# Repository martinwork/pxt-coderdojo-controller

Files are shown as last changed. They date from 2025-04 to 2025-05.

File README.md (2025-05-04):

# pxt-coderdojo-controller
This is an open-source, low-cost, do-it-yourself game controller for the micro:bit. You cannot purchase a finished product. Instead, you'll need to gather all the components and assemble it yourself or with your class.  
[Read more in the hardware section for a detailed building guide](https://github.com/jimd80/pxt-coderdojo-controller/tree/main/hardware)

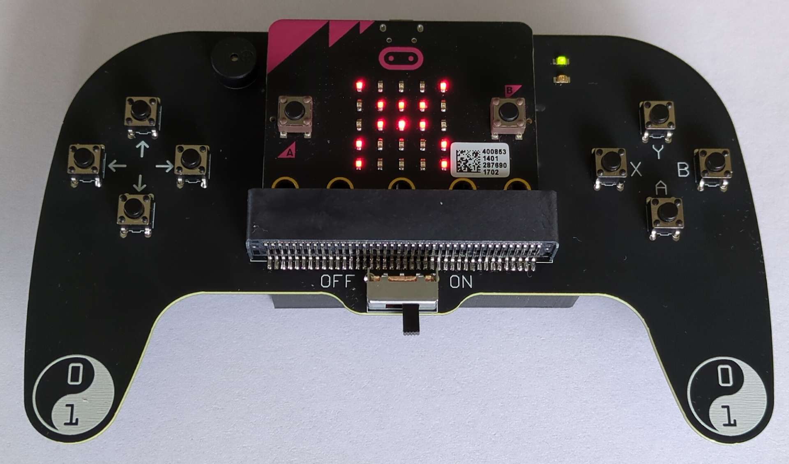
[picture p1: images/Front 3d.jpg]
Controller front image

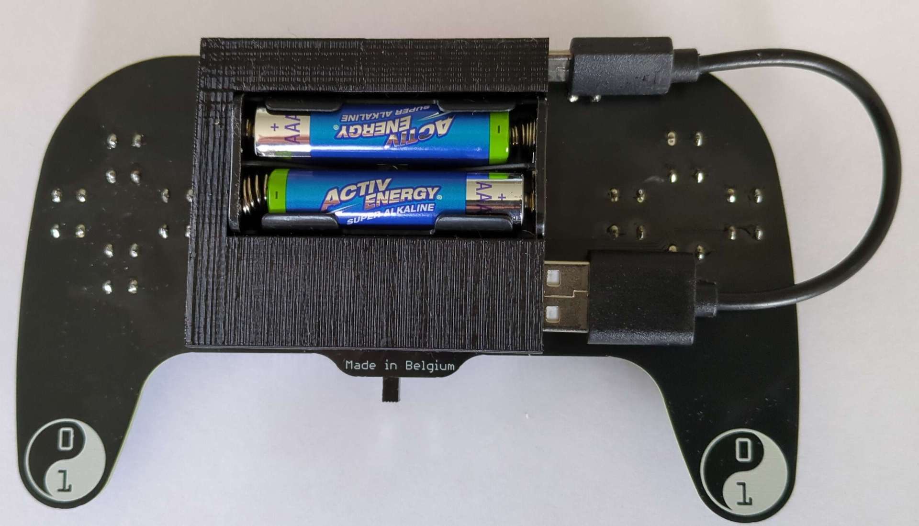
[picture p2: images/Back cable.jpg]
Controller back image


## Features
* 8 buttons: Up, Down, Left, Right, X, Y, A, B
* 2x AAA batteries, On/Off switch, and LED indicator
* Built-in speaker and customizable red LED
* Micro USB cable storage compartment
* Protection against short circuits and incorrect I/O usage
* Compatible with micro:bit v1.x and v2.x
* Over 100 hours of battery life

## Usage
Creating software for this controller can be done with [Microsoft MakeCode for micro:bit](https://makecode.microbit.org/)
* Create a new project and give it a name of your choice
* Click on Extensions in the block menu
* Search for coderDojo-controller and click on the thumbnail

After adding the extension, you'll find the specific blocks for this controller under ``Dojo Controller``

The blocks work the same as the standard micro:bit A and B buttons and can be used in 2 ways:  

* An event driven approach: use the ``on button pressed`` block. The code inside gets executed when a button is pressed/clicked. The behaviour can be changed to execute the code if the button is released instead.

```blocks
coderDojoController.onButtonPress(CoderDojoButtonID.X, CoderDojoButtonEvent.Pressed, function () {
    coderDojoController.setRedLed(CoderDojoLedState.On)
})
```

```blocks
coderDojoController.onButtonPress(CoderDojoButtonID.X, CoderDojoButtonEvent.Released, function () {
    coderDojoController.setRedLed(CoderDojoLedState.Off)
})
```

* Alternatively, a loop driven approach can be used with a standard ``if`` block combined with the ``button is pressed`` function. The code inside the ``if`` block will be executed multiple times, as long as the button is being pressed.

```blocks
basic.forever(function () {
    if (coderDojoController.buttonIsPressed(CoderDojoButton.X, CoderDojoButtonState.Pressed)) {
        coderDojoController.setRedLed(CoderDojoLedState.On)
    } else {
        coderDojoController.setRedLed(CoderDojoLedState.Off)
    }
})
```

Note that the A and B buttons on the micro:bit have the same function as the A and B buttons on the controller. You can use the extension without the controller hardware and have the extra buttons available when plugged into the controller.

## Build
cd into project folder  
npm install pxt  
pxt target microbit  
pxt gendocs --locs  
if needed: update translations in _locales/  
pxt build  

## Supported targets

* for PXT/microbit
(The metadata above is needed for package search.)

## License

MIT  

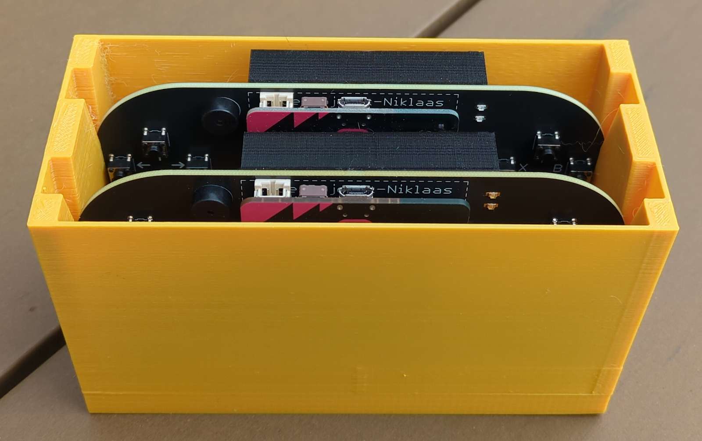
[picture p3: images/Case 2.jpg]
PCB Components


```package
coderdojo-controller=github:jimd80/pxt-coderdojo-controller
```

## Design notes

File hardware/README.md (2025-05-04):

## Hardware building guide
The (empty) PCB can be easily manufactured by any PCB company, for example JLCPCB which is known as the cheapest. The cable holder at the back can be 3D printed with any 3D printer, for example the affordable Creality Ender V2 or V3.

Other parts can be ordered at various electronics suppliers such as LCSC, Aliexpress, Digikey, Farnell, ... The most difficult part to source will be the Micro:bit EDGE Connector. This needs to be the horizontal SMD type. Start finding this connector first before deciding to build this project.

Soldering can be done with (Lead free) soldering paste and a reflow oven, or if you are a bit handy it can also be done with a classical soldering iron, lead-free soldering wire and some flux. In that case it will be handy to have something to keep the parts in place while soldering, such as a screwdriver.

## Tools needed

You'll needs some tools and skills to build this project.
- A soldering iron and lead-free soldering wire
- Optionally, a reflow oven OR a hot air gun. Using this option you'll also need lead-free solder paste, such as Chipquik TS391SNL
- Recommended: Flux, such as Chipquik SMD291NL
- Cutting plier

## Step 1: Ordering the parts
Check out the [Bill of materials](https://github.com/jimd80/pxt-coderdojo-controller/blob/main/hardware/Bom.ods?raw=true). Parts can be ordered at various suppliers.

Part number      |Reference	            |Description                      |Qty|Price|Order link example|
:----------------|:---------------------|:--------------------------------|--:|----:|:-----------------|
R1,2,3,4,8,9     |Res 1K SMD0805        |Resistor 1K / 1% / 0,1W / 0805   |  6|€0.06|[LCSC](https://www.lcsc.com/product-detail/Chip-Resistor-Surface-Mount_YAGEO-RC0805FR-071KL_C95781.html)|
R5               |Res 100R SMD0805      |Resistor 100R / 1% / 0,1W / 0805 |  1|€0.01|[LCSC](https://www.lcsc.com/product-detail/Chip-Resistor-Surface-Mount_YAGEO-RC0805FR-07100RL_C105577.html)|
R6,7             |Res 470R SMD0805      |Resistor 470R / 1% / 0,1W / 0805 |  2|€0.02|[LCSC](https://www.lcsc.com/product-detail/Chip-Resistor-Surface-Mount_YAGEO-RC0805FR-07470RL_C114564.html)|
C1,2 (Optional)  |Cap 4u7 16v SMD1206   |Capacitor 4u7 / 16V / SMD 1206   |  2|€0.04|[LCSC](https://www.lcsc.com/product-detail/Multilayer-Ceramic-Capacitors-MLCC-SMD-SMT_Samsung-Electro-Mechanics-CL31B475KBHNNNE_C51205.html)|
LD1              |LED Red SMD0805       |Led Red SMD 0805                 |  1|€0.02|[LCSC](https://www.lcsc.com/product-detail/LED-Indication-Discrete_XINGLIGHT-XL-2012SURC_C965812.html)|
LD2              |LED Green SMD0805     |Led Green SMD 0805               |  1|€0.02|[LCSC](https://www.lcsc.com/product-detail/LED-Indication-Discrete_XINGLIGHT-XL-2012UGC_C965815.html)|
F1               |Polyfuse 500mA SMD1812|Polyfuse 30V / 500mA / SMD 1812  |  1|€0.08|[Aliexpress](https://www.aliexpress.com/item/1005006431435556.html)|
BUZ1             |9042 16R Passive      |Passive piezo sounder 3-5v       |  1|€0.19|[Aliexpress](https://www.aliexpress.com/item/1005006230919996.html)|
SW1,2,3,4,6,7,8,9|Pushbutton 6x6x5mm    |Pushbutton (on)-off 6x6x5mm      |  8|€0.05|[Aliexpress](https://www.aliexpress.com/item/1005001897291190.html)|
SW5              |Switch SS-12F23       |Slider switch 50v/0,5A spdt      |  1|€0.08|[Aliexpress](https://www.aliexpress.com/item/1005004508647910.html)|
BATT1            |2XAAA Battery Box     |Battery holder 2x AAA center hole|  1|€0.36|[Aliexpress](https://www.aliexpress.com/item/1005006274732583.html)|
J1               |Edge connector hor SMD|Micro:bit edge connector SMD/hor |  1|€0.85|[Aliexpress](https://www.aliexpress.com/item/1005006206948907.html)|
Other            |SMTSO M3 1ET          |SMD M3 Nut Length 1,5 + 1mm      |  1|€0.22|[Aliexpress](https://www.aliexpress.com/item/1005007226371037.html)|
Other            |Screw M3x6            |Screw M3x6 countersunk           |  1|€0.04|[Aliexpress](https://www.aliexpress.com/item/4000983507018.html)|

- C1 and C2 are not really required but can avoid software resets when shaking the controller heavilly
- BUZ1 is not required if using a micro:bit v2 or if sound is not preferred
- The most difficult part to find will be the EDGE connector, this needs to be the horizontal SMD version, and needs to look exactely like this

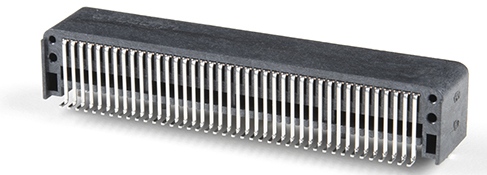
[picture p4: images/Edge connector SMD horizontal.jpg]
EDGE Connector


## Step 2: Ordering the PCB
The PCB (without components) needs to be manufactored by a company. These are the instructions for JLCPCB.
- Go to (https://jlcpcb.com)
- Choose "Add gerber file" and upload [CoderDojo Controller JLCPCB order.zip](https://github.com/jimd80/pxt-coderdojo-controller/blob/main/hardware/CoderDojo%20Controller%20JLCPCB%20order.zip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)
- Select your desired quantity (the more the cheaper per board)
- Change PCB Color to Black
- Change Surface Finish to LeadFree HASL (If ROHS is required in your country, always the case for the EU)
- Choose Mark on PCB: Remove Mark  
All other options are oke by default. Complete the order process.

## Step 3: 3D Print the cable holder
This step is not required if you don't want to have the cable storage at the back of the controller. In that case, the screw needs to be M3x5 instead of M3x6.
- Download [Cable holder 3D Print.stl](https://github.com/jimd80/pxt-coderdojo-controller/blob/main/hardware/CAD%20Files/Cable%20holder%203D%20Print.stl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)
- Process the file in your slicer. Recommended layer height is 0.2mm and recommended speed is 50mm/s
- Print it, preferable with black PETG as this is more fire resistant than PLA or ABS

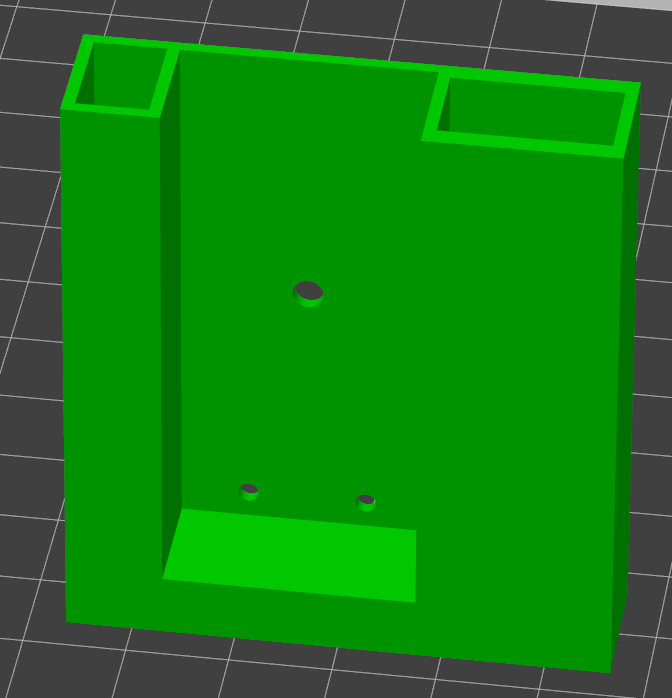
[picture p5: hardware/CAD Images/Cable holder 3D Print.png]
Cable holder


## Step 4: Solder the SMD parts
In the [Bill of materials](https://github.com/jimd80/pxt-coderdojo-controller/blob/main/hardware/Bom.ods?raw=true) you'll find which parts belongs to which part numbers printed on the PCB (such as R1, C1, ...). Only for the 2 LED's the direction of the part (polarity) matters. There is usually an indicator, like a small green dot or a line) that should point in the direction of the arrow on the PCB.
Also solder the special M3 nut in the middle. Avoid putting excess solder at the back side as that surface needs to stay flat for the battery box.

Soldering SMD parts can be done in several ways, there are many tutorials online such as https://www.youtube.com/watch?v=hoLf8gvvXXU or https://www.youtube.com/watch?v=fYInlAmPnGo

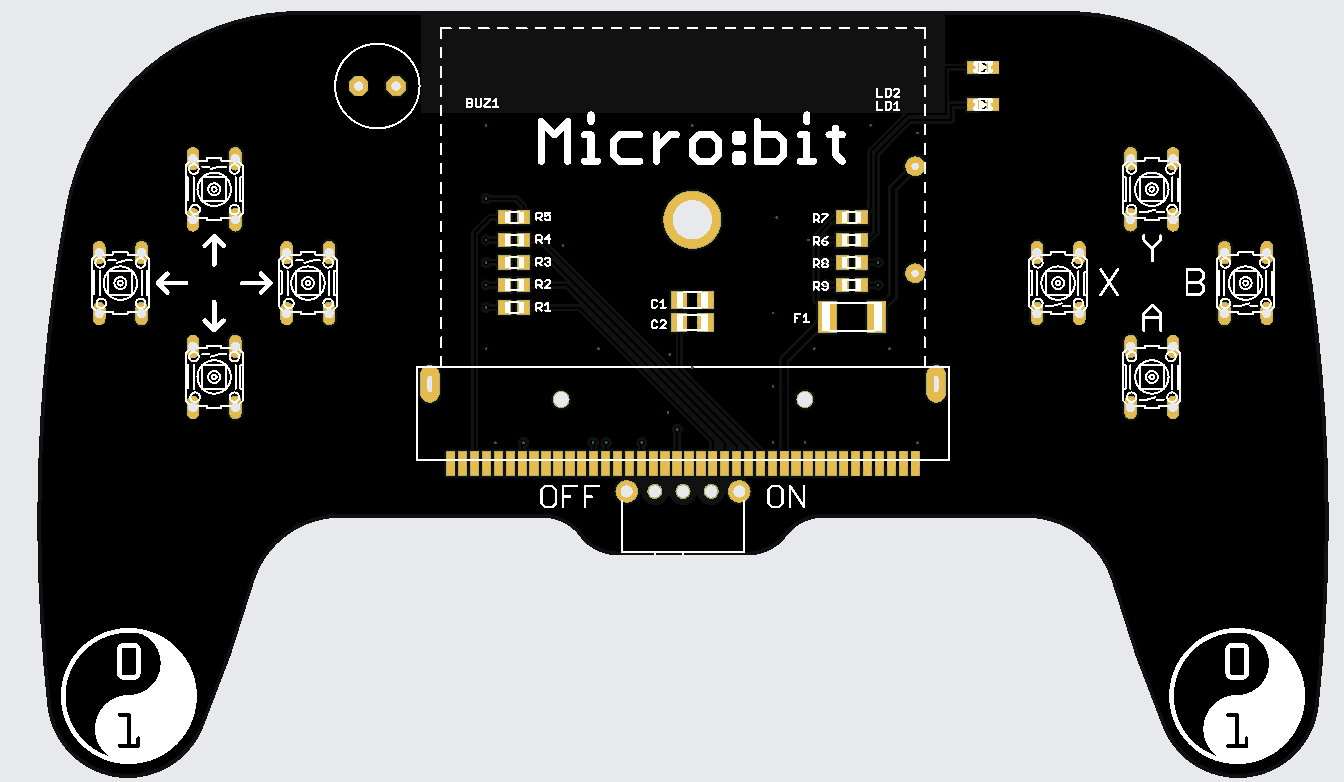
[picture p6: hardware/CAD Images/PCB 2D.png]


## Step 5: Solder the Edge connector
The EDGE connector is preferably soldered with a soldering iron as it is not clear if it can withstand 240 degrees hot air required for lead-free soldering. Use extra flux to create smooth joints. After soldering, remove the flux with isopropyl alcohol.

## Step 6: Solder the through hole parts
Next, solder the switches and the speaker with a soldering iron and soldering wire. Cut off the excess leads and smoothen the sharp edges at the back with a small file or sanding paper (be careful to not damage the pcb)

## Step 7: Mount the battery box and cable holder
Next, put the battery box through the printed cable holder at the back of the pcb, and fix it with a 6mm M3 screw (conical head). Then, solder the 2 leads of the battery box and cut the excess wire. Note that the leads of the battery box require decent heating to attach to the solder, as these leads are not pre-tinned as you would normally expect. On my prototype, I had regular software resets due to a poor contact due to insufficient heating. The soldering joint looked good, but was not really bounded.

## Step 8: Ready to power up
Always make sure to put the power switch to the OFF position when placing or removing the micro:bit.

Enjoy!

## Optional: Print a storage case
STL files are available in the CAD Files folder for printing a storage case from 2 till 7 controllers. The bottom notch will prevent the contoller to fit nicely when the power button is still on (preventing battery drain)  

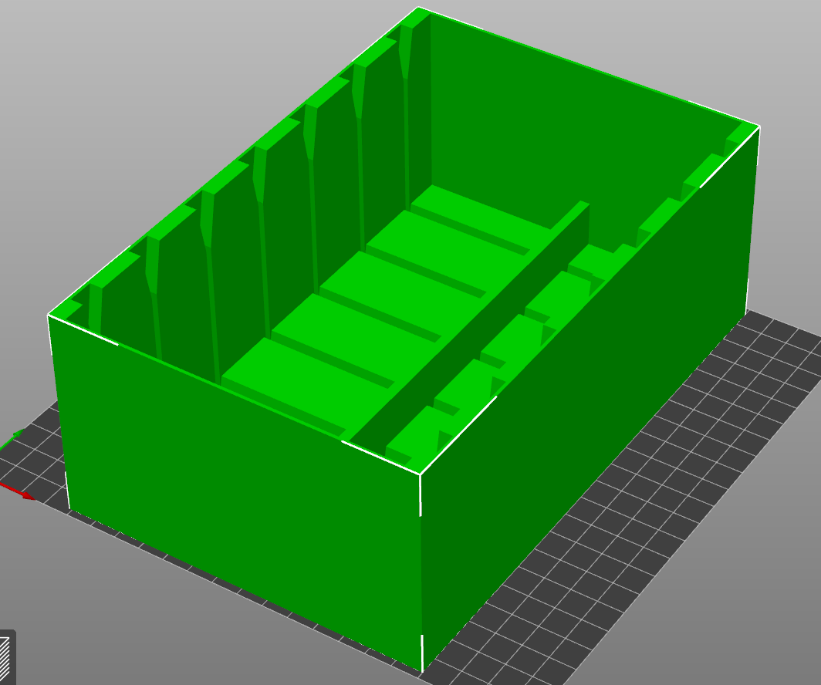
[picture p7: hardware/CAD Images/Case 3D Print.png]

PCB Components

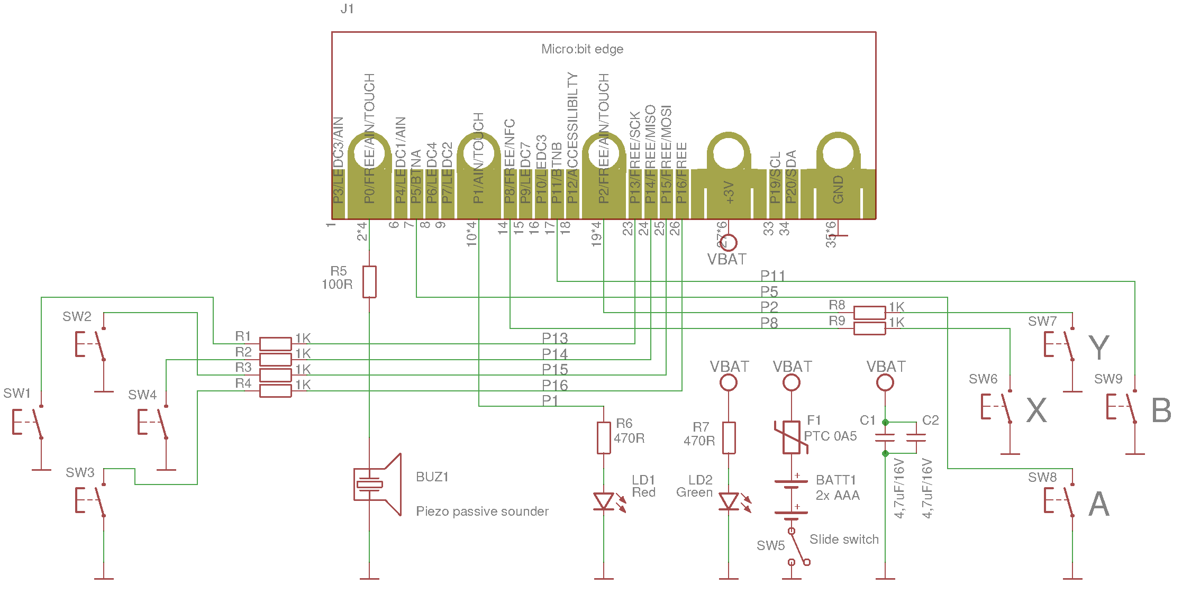
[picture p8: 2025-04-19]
hardware/CAD Images/Schematic.png

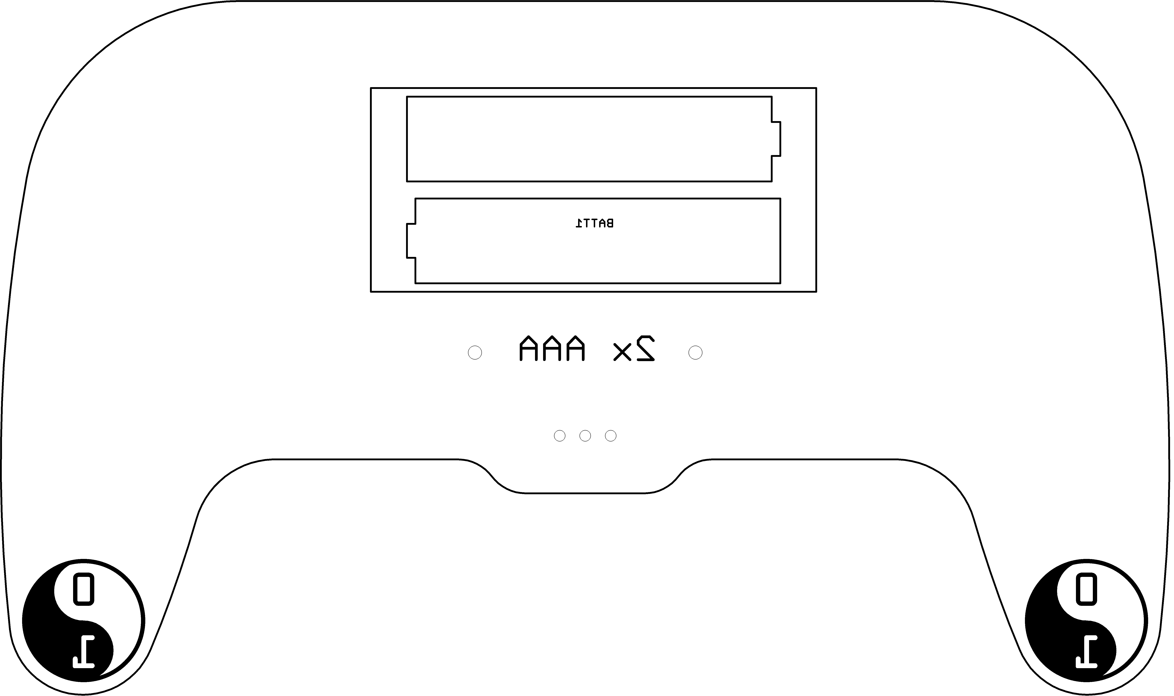
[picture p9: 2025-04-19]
hardware/CAD Images/silkscreen_bottom.png

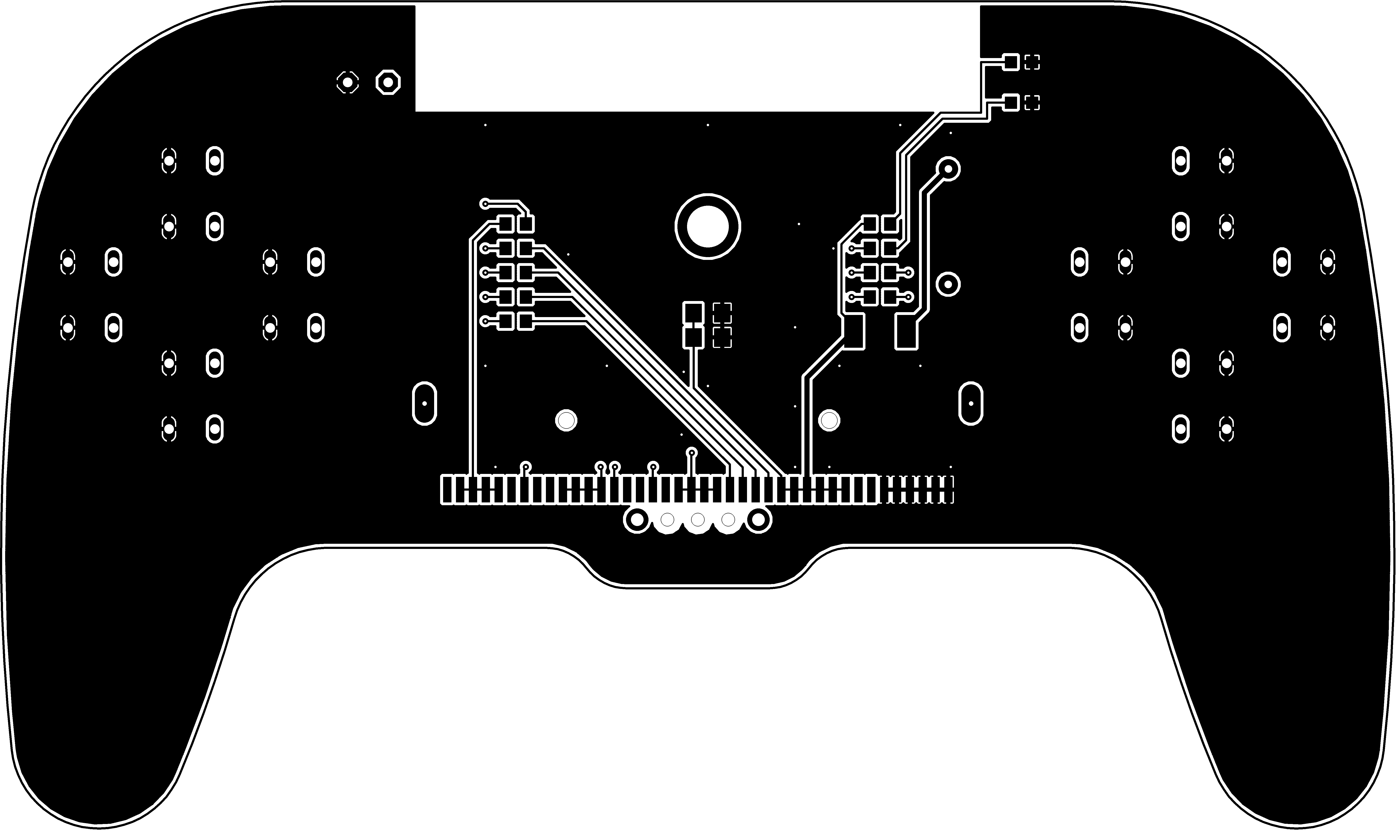
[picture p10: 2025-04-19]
hardware/CAD Images/copper_layer_1_top.png

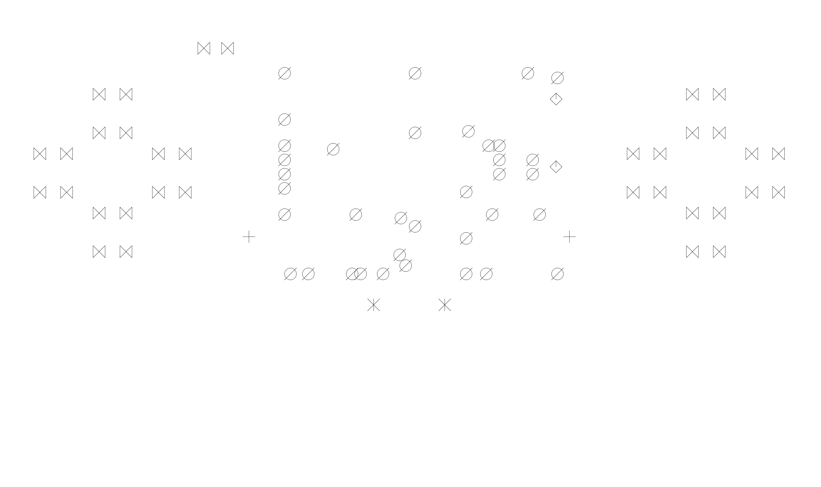
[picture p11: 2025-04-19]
hardware/CAD Images/plated_drills.png

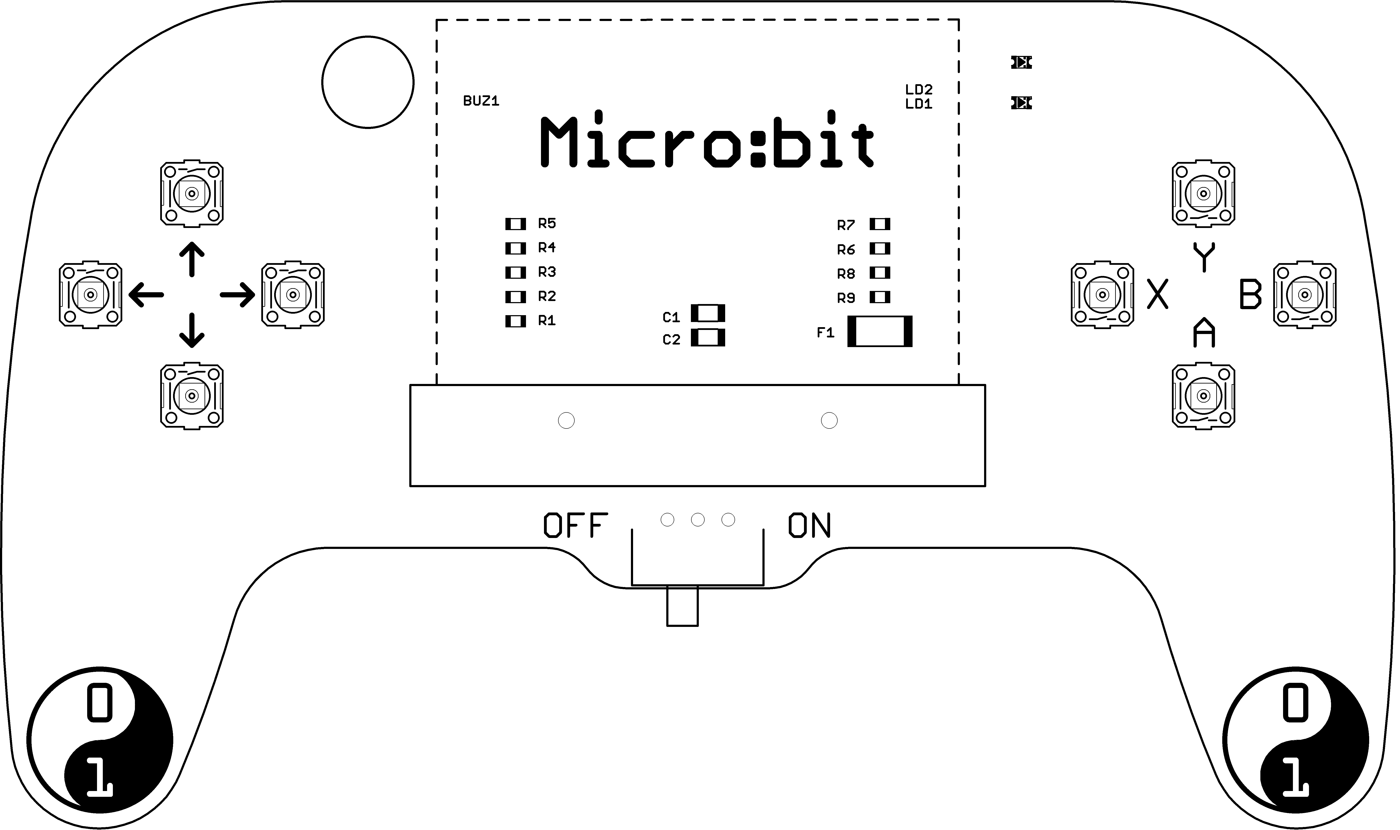
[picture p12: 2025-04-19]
hardware/CAD Images/silkscreen_top.png

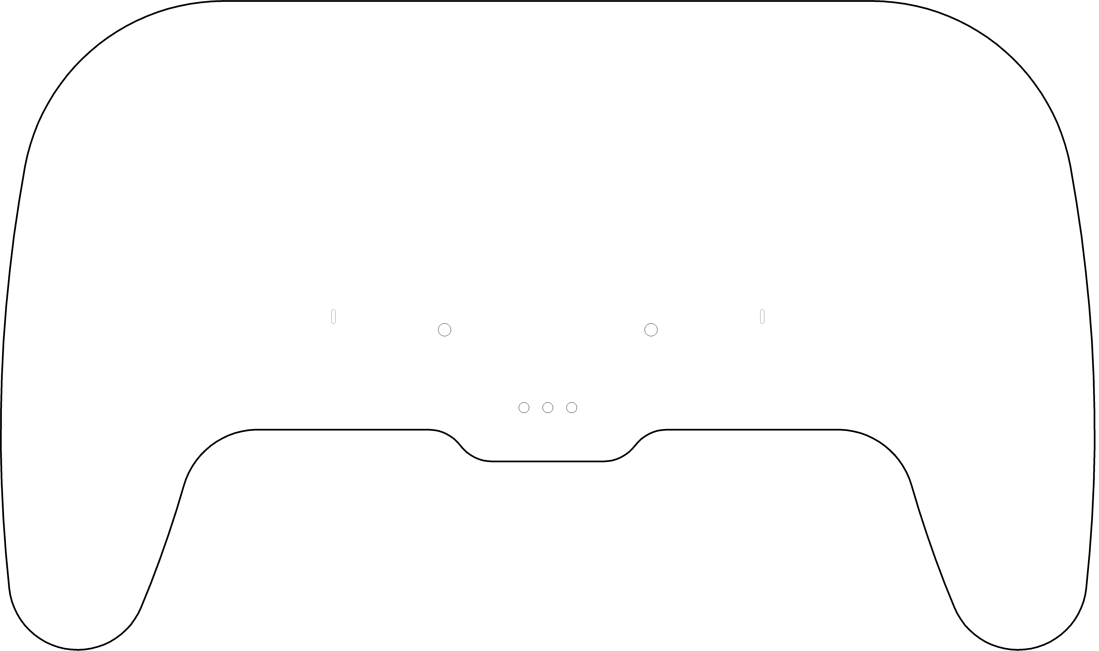
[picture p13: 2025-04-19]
hardware/CAD Images/mechanical.png

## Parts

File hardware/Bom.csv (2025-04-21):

Part(s) | Reference | Description | Supplier | Supplier ref | Quantity | Estimated price | Subtotal
R1, R2, R3, R4, R8, R9 | Res 1K SMD0805 | 1K / 1% / 0,1W / 0805 | LCSC | C95781 | 6 | € 0,01 | € 0,06
R5 | Res 100R SMD0805 | 100R / 1% / 0,1W / 0805 | LCSC | C105577 | 1 | € 0,01 | € 0,01
R6, R7 | Res 470R SMD0805 | 470R / 1% / 0,1W / 0805 | LCSC | C114564 | 2 | € 0,01 | € 0,02
C1, C2 (Optional) | Cap 4u7 16v SMD1206 | Capacitor ceramic 4u7 / 16V / SMD 1206 | LCSC | C51205 | 2 | € 0,02 | € 0,04
LD1 | LED Red SMD0805 | Led Red 625nm / 120 deg / 20mA / 2V / SMD 0805 | LCSC | C965812 | 1 | € 0,02 | € 0,02
LD2 | LED Green SMD0805 | Led Green 568nm / 120 deg / 20mA / 2,2V / SMD 0805 | LCSC | C965815 | 1 | € 0,02 | € 0,02
F1 | Polyfuse 500mA SMD1812 | Polyfuse 30V/500mA | Aliexpress | https://www.aliexpress.com/item/1005006431435556.html | 1 | € 0,08 | € 0,08
BUZ1 | 9042 16R Passive | Passive piezo sounder 3-5v | Aliexpress | https://www.aliexpress.com/item/1005006230919996.html | 1 | € 0,19 | € 0,19
SW1,2,3,4,6,7,8,9 | Pushbutton 6x6x5mm | Pushbutton (on)-off 6x6mm print height 5mm | Aliexpress | https://www.aliexpress.com/item/1005001897291190.html | 8 | € 0,05 | € 0,40
SW5 | Switch SS-12F23 | 50v/0,5A spdt | Aliexpress | https://www.aliexpress.com/item/1005004508647910.html | 1 | € 0,08 | € 0,08
BATT1 | 2XAAA Box | Battery holder 2x AAA with center hole | Aliexpress | https://www.aliexpress.com/item/1005006274732583.html | 1 | € 0,36 | € 0,36
J1 | Edge connector horizontal SMD | Micro:bit edge connector | Aliexpress | https://www.aliexpress.com/item/1005006206948907.html | 1 | € 0,85 | € 0,85
Other 1 | SMTSO M3 1ET | SMD M3 Nut Length 1,5 + 1mm | Aliexpress | https://www.aliexpress.com/item/1005007226371037.html | 1 | € 0,22 | € 0,22
Other 2 | Screw M3x6 | Screw M3x6 countersunk | Aliexpress | https://www.aliexpress.com/item/4000983507018.html | 1 | € 0,04 | € 0,04
Other 3 | Cable holder | 3D Printed Cable Holder PETG Black |  | Cable holder 3D Print.stl | 1 | € 0,50 | € 0,50
Other 4 | PCB | CoderDojo Controller circuit board | JLCPCB | CoderDojo Controller JLCPCB order.zip | 1 | € 1,00 | € 1,00
Total |  |  |  |  |  |  | € 3,89

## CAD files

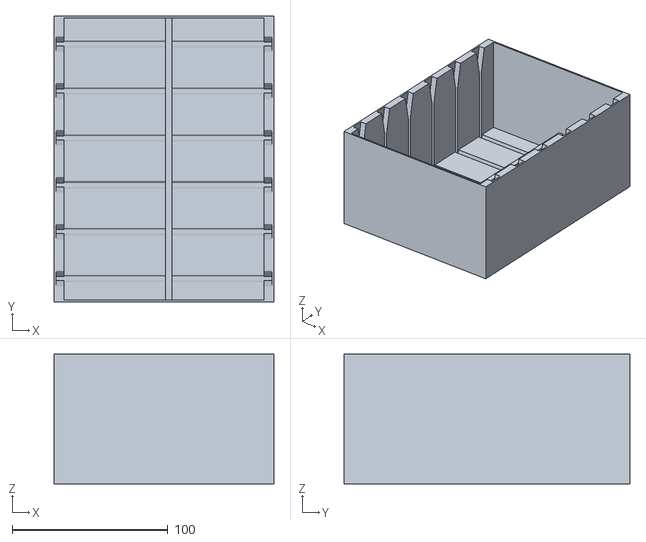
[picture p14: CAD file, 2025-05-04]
hardware/CAD Files/Microbit gamectl holder 6.stl
140.9 x 183.5 x 83.2

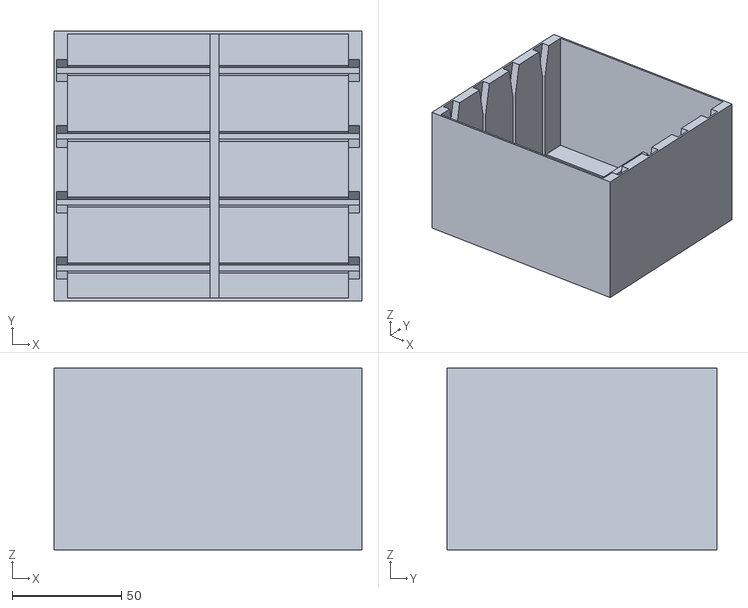
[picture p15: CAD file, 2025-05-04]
hardware/CAD Files/Microbit gamectl holder 4.stl
140.9 x 123.3 x 83.2

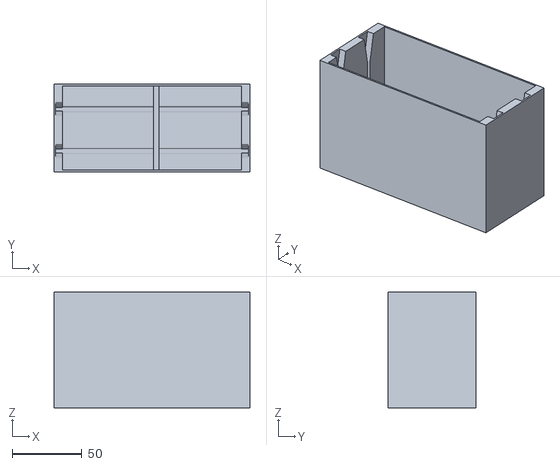
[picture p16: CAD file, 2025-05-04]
hardware/CAD Files/Microbit gamectl holder 2.stl
140.9 x 63.1 x 83.2

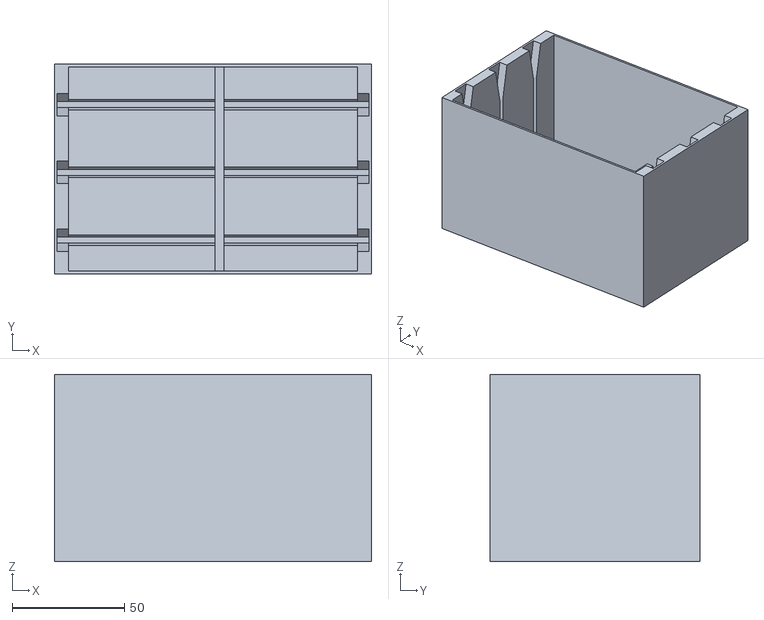
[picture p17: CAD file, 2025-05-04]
hardware/CAD Files/Microbit gamectl holder 3.stl
140.9 x 93.2 x 83.2

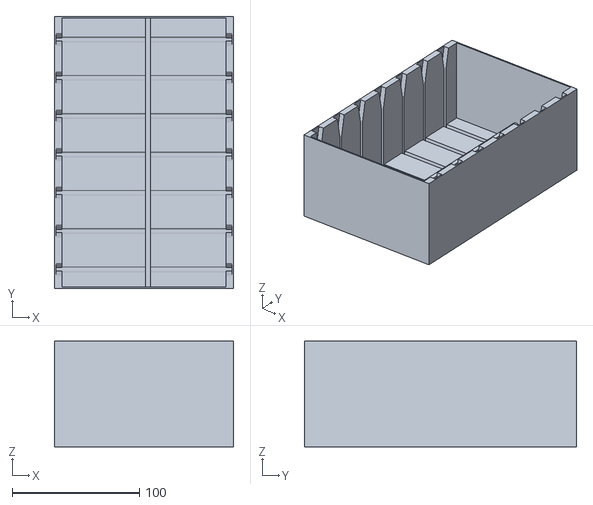
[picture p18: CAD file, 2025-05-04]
hardware/CAD Files/Microbit gamectl holder 7.stl
140.9 x 213.6 x 83.2

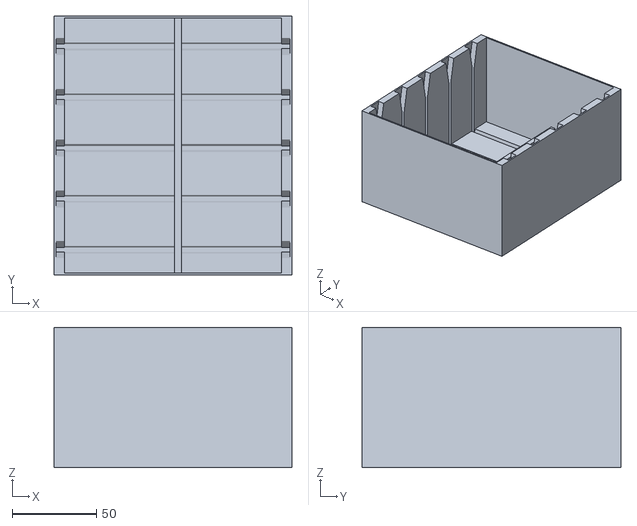
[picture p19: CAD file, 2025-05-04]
hardware/CAD Files/Microbit gamectl holder 5.stl
140.9 x 153.4 x 83.2

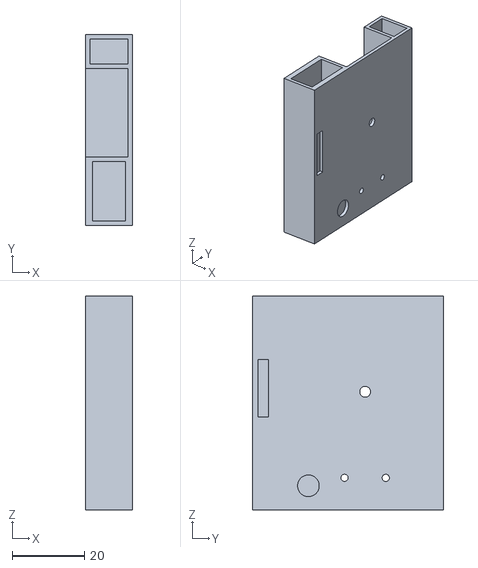
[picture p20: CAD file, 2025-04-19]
hardware/CAD Files/Cable holder 3D Print.stl
12.9 x 52.8 x 59.2

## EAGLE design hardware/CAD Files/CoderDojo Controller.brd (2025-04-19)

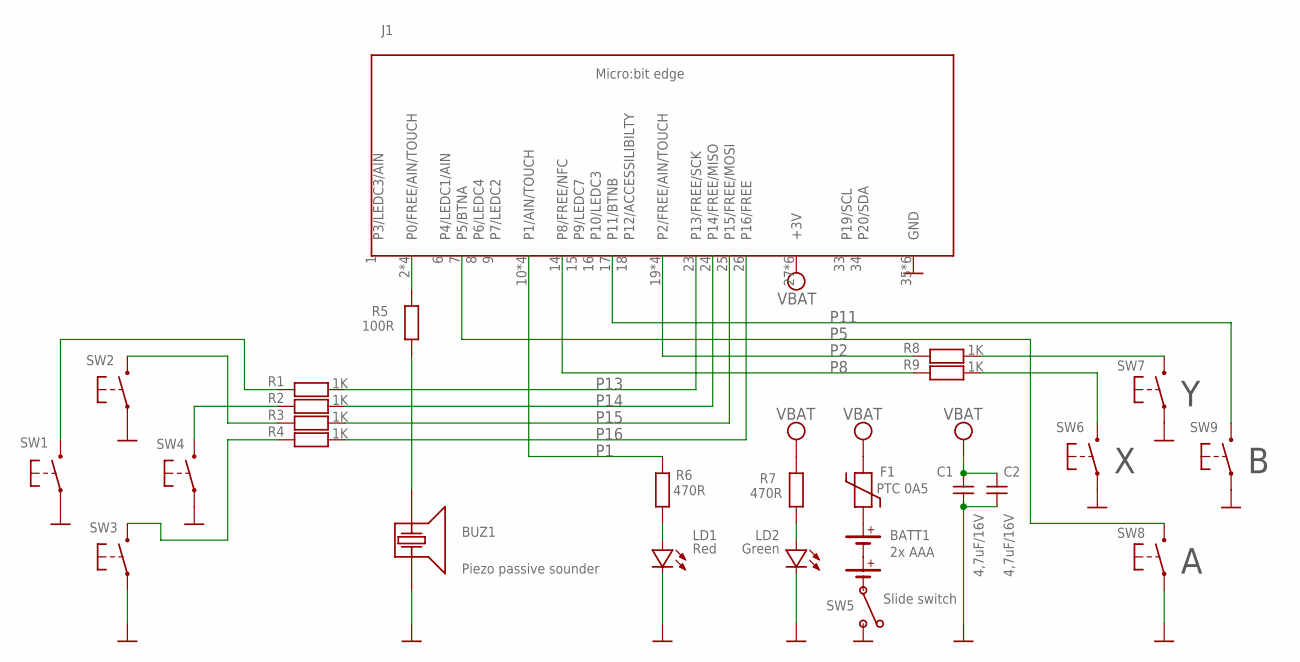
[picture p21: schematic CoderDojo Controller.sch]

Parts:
BATT1: CJ2XAAA; SOCKET_2XAAA
BUZ1: CBUZ9; BUZZER9
C1, C2: CC4U7A; CAP_1206
F1: CFPOLY0A5B; RES_1812
J1: CJMBITH; SOCKET_MBIT_H
LD1: CDLEDRDC; LED_0805
LD2: CDLEDGNC; LED_0805
R1, R2, R3, R4, R8, R9: CR1KA; RES_0805
R5: CR100RA; RES_0805
R6, R7: CR470RA; RES_0805
SW1, SW2, SW3, SW4, SW6, SW7, SW8, SW9: CSWPUSHA5; SWITCH_PUSH_5MM
SW5: CSWSS12F23; SWITCH_SS12F23

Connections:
GND: BUZ1.2, C1.1, C2.1, J1.35 (GND), J1.36 (GND), J1.37 (GND), J1.38 (GND), J1.39 (GND), J1.40 (GND), LD1.C, LD2.C, SW1.3, SW1.4, SW2.3, SW2.4, SW3.3, SW3.4, SW4.3, SW4.4, SW5.3 (B), SW6.3, SW6.4, SW7.3, SW7.4, SW8.3, SW8.4, SW9.3, SW9.4
unnamed: R9.2, SW6.1 (S), SW6.2 (S)
unnamed: R8.2, SW7.1 (S), SW7.2 (S)
unnamed: R2.1, SW4.1 (S), SW4.2 (S)
unnamed: R3.1, SW2.1 (S), SW2.2 (S)
unnamed: J1.2 (P0/FREE/AIN/TOUCH), J1.3 (P0/FREE/AIN/TOUCH), J1.4 (P0/FREE/AIN/TOUCH), J1.5 (P0/FREE/AIN/TOUCH), R5.2
unnamed: BUZ1.1, R5.1
unnamed: BATT1.POS (+), F1.1
unnamed: BATT1.NEG (-), SW5.2 (CEN)
unnamed: LD2.A, R7.1
unnamed: LD1.A, R6.1
unnamed: R1.1, SW1.1 (S), SW1.2 (S)
unnamed: R4.1, SW3.1 (S), SW3.2 (S)
P1: J1.10 (P1/AIN/TOUCH), J1.11 (P1/AIN/TOUCH), J1.12 (P1/AIN/TOUCH), J1.13 (P1/AIN/TOUCH), R6.2
P2: J1.19 (P2/FREE/AIN/TOUCH), J1.20 (P2/FREE/AIN/TOUCH), J1.21 (P2/FREE/AIN/TOUCH), J1.22 (P2/FREE/AIN/TOUCH), R8.1
P5: J1.7 (P5/BTNA), SW8.1 (S), SW8.2 (S)
P8: J1.14 (P8/FREE/NFC), R9.1
P11: J1.17 (P11/BTNB), SW9.1 (S), SW9.2 (S)
P13: J1.23 (P13/FREE/SCK), R1.2
P14: J1.24 (P14/FREE/MISO), R2.2
P15: J1.25 (P15/FREE/MOSI), R3.2
P16: J1.26 (P16/FREE), R4.2
VBAT: C1.2, C2.2, F1.2, J1.27 (+3V), J1.28 (+3V), J1.29 (+3V), J1.30 (+3V), J1.31 (+3V), J1.32 (+3V), R7.2

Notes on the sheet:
Piezo passive sounder

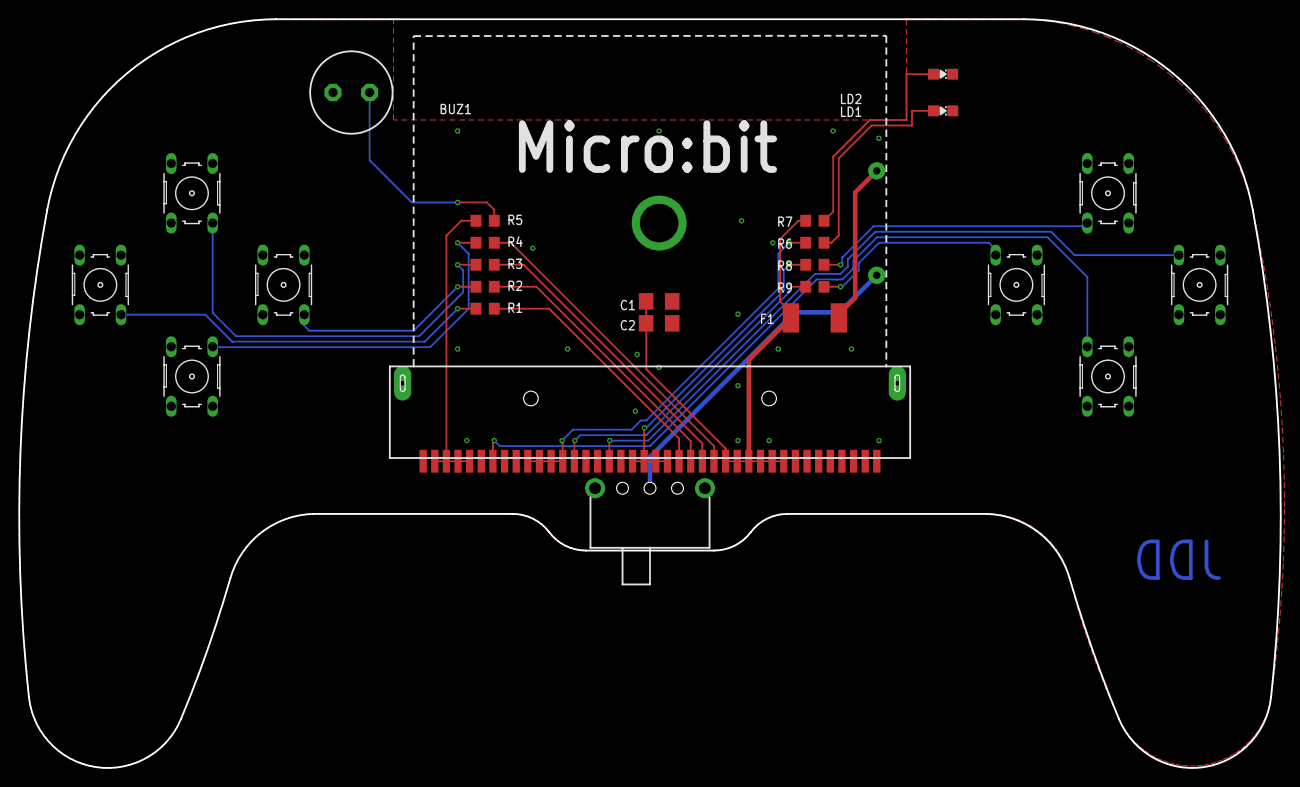
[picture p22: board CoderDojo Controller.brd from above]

Board: 2 copper layers, 137.7 x 81.7 mm, 26 parts (1 on the bottom side), 23 nets.

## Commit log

2025-04-19 Added hardware files
    [Bom.csv, Bom.ods, Cable holder 3D Print.stl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]
2025-04-19 corrected csv
    [Bom.tsv]
2025-04-19 undo tsv
    [Bom.csv]
2025-04-21 Added bom and images in doc
    [Bom.csv, Bom.ods]
2025-05-04 Completed documentation
    [Microbit gamectl holder 2.stl, Microbit gamectl holder 3.stl, Microbit gamectl holder 4.stl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]
